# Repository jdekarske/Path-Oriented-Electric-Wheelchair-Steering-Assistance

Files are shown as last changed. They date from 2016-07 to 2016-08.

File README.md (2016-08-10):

# Path-Oriented-Electric-Wheelchair-Steering-Assistance
* See abstract for research background and see [TJOE](idkyet) for full research paper.

## Starting from scratch.
* See the bill of materials in appendix of paper for parts used in this project. 
* The "backup image" file can be flashed to an sd card using [this tutorial](http://computers.tutsplus.com/articles/how-to-flash-an-sd-card-for-raspberry-pi--mac-53600) or your favorite method.

## Adding to an existing system.
* Install the OpenCV library using [this tutorial](http://www.pyimagesearch.com/2016/04/18/install-guide-raspberry-pi-3-raspbian-jessie-opencv-3/).

## Using the scripts.
* Add run command `sudo python <script directory> &` to `etc/profile`, use ampersand to run script in background.
* Use `sudo raspi-config` and switch to "auto login command line" or errors will occur! 
* Use `live_sidewalk_recogize.py` for the intended application described by the research documents.
* Use `sidewalkrecognize.py` to analyze images and adjust range parameters.
* Use `videowatcher.py` to see frame by frame if omxplayer isn't working.
* Use `vsidewalkrecognize.py` to analyze videofiles.

# TODO (`live_sidewalk_recognize.py`):
* Find more graceful way to use `onbuttonpress()`.
* Add cliff detection. When the centroid falls below a certain vertical coordinate.
* Add shadow detection. See article: ["Shadow Detection and Removal from a Single Image Using LAB Color Space"](url=http://www.degruyter.com/view/j/cait.2013.13.issue-1/cait-2013-0009/cait-2013-0009.xml)
* Improve framerate/optimize.

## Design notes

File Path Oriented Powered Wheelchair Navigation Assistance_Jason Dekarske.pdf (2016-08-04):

Path Oriented Powered Wheelchair Navigation Assistance
Jason Dekarske, Devin R. Berg
University of Wisconsin – Stout

Introduction: Electric wheelchairs can greatly improve an individual’s life and independence. The literature indicates that 40% of patients using wheelchairs found it “difficult or impossible” to steer an electric wheelchair and up to half of patients would find it beneficial to have an added navigation system (Fehr et al., 2000). Wheelchair navigation systems, however, have seldom been implemented due to expense of the associated technologies and complexity of the components required. Horn summarizes that navigation systems used in “smart wheelchairs” during the past few decades include technologies such as infrared, sonar, laser, radar, and physical modalities (Horn, 2012). The research presented here aims to help people with disabilities navigate in a daytime, suburban or urban environment. Using a simple color camera, differences in the color and shape of the environment can be used to isolate a navigable path. Like lane keeping systems used in modern cars, the design presented here makes use of a passive interference system, to provide the user with direct navigational control, but aids in steering (Yu et al.,2008).

Materials and Methods: To minimize system cost, the materials selected are those commonly used in opensource hardware design. The Raspberry Pi 3 is used as the computational device with the Raspi camera module attached. The board runs Raspbian Jessie, the most recent operating system and a 10 Ah battery bank provides power. To analyze input, the Python programming language was used along with the OpenCV library to process images. Finally, as a proof of concept, an LED array provides visual feedback to the user. To identify the sidewalk, the software removes anything in the picture that doesn’t share similar appearance characteristics, then calculates the position of the centroid of the remaining shape. This determines whether the user is on path. To test the device, it was attached to a powered wheelchair and driven down the sidewalk. In one case, the wheelchair was manually driven according strictly to the path shown by the LED array. In another case, the wheelchair was pivoted from side to side to analyze the reaction by the device

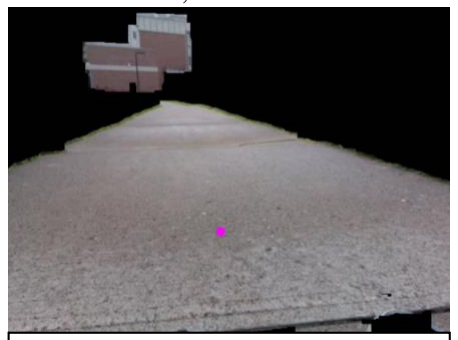
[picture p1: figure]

Results and Discussion: Case one was successful in terms of intervention.
Only when turning corners or navigating a split in the path did the subject have to divert from the device’s suggestion. Case two demonstrated that the user was able to complete a full turn with consistent tracking of the sidewalk for the entirety. In addition, the device kept accurate error logs and reported an average of near 6 frames per second over multiple trials while simultaneously recording video. The battery supplies power for approximately 5 hours, but the system could be integrated into the wheelchair’s power.

Conclusions: This navigation system represents a tool to help people that
use wheelchairs navigate their surroundings with greater confidence. This
prototype is sufficiently capable of indicating which part of the
environment is navigable. Implementation of this system can be modified to include an intervention into the control system of a powered wheelchair.

Acknowledgements: This work was completed as part of the Interdisciplinary Research Experiences in Robotics for Assistive Technology REU funded through NSF Award # CNS-1560219.

References:
Fehr, L., Langbein, W. E., & Skaar, S. B. (2000). Adequacy of power wheelchair control interfaces for persons with severe disabilities: A clinical survey. Journal Of Rehabilitation Research & Development, 37(3), 353.
Horn, O. (2012). Smart Wheelchairs: past and current trends. Systems and Computer Science, pp. 1-6.
Yu, B., Zhang, W., & Cai, Y. (2008). A Lane Departure Warning System based on Machine Vision. IEEE Pacific-Asia Workshop on Computational Intelligence and Industrial Application, pp. 197-201.

Figure 1. This screengrab shows the output of a sidewalk after calculating the centroid (pink circle). Only the largest part of the visible mask is considered.

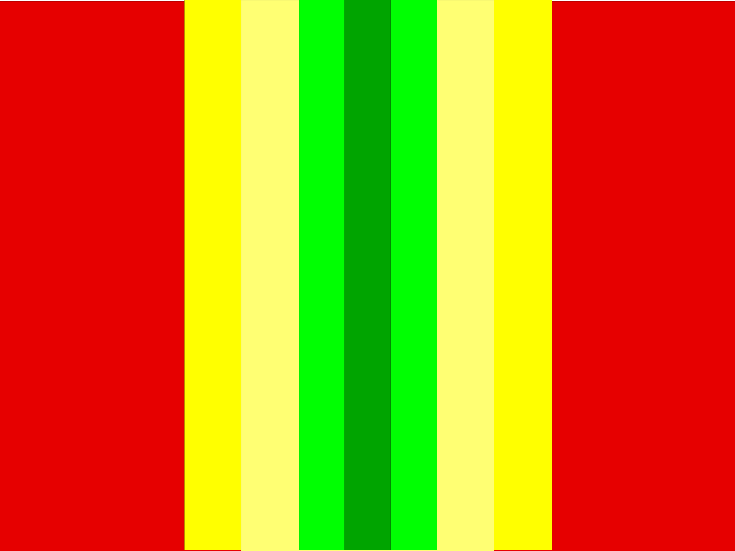
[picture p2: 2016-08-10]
pics/ranges.png

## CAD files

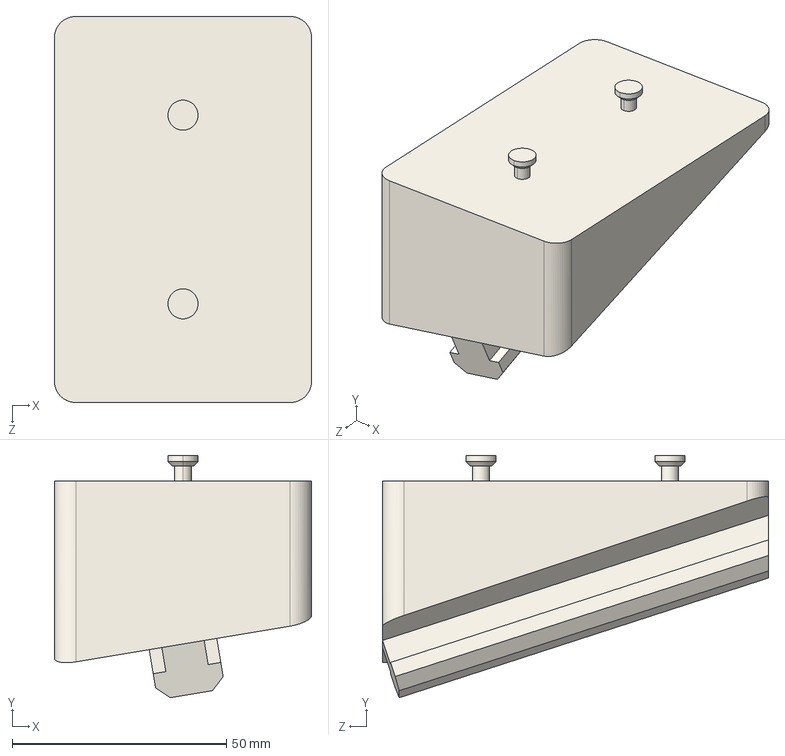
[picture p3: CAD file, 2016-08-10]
Raspi_mount.STEP
60.0 x 56.5 x 90.0 mm

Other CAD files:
Raspi_mount.SLDPRT

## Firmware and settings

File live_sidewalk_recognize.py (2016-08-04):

import RPi.GPIO as GPIO
import time
import io
import numpy as np
import cv2
import picamera
import logging

global menuv
menuv = 0
global buttonpress
buttonpress = 0

#logging setup
logging.basicConfig(format='\n%(asctime)s %(message)s', filename='/home/pi/REU/Path-Oriented-Electric-Wheelchair-Steering-Assistance/Output/data.log',level=logging.DEBUG)
logging.info('----Startup----')

#pin setup
GPIO.setmode(GPIO.BOARD)## Use board pin numbering
button   = 3
red_r    = 35
yellow_r2= 33
yellow_r = 31
green_r  = 29
green    = 23
green_l  = 21
yellow_l = 19
yellow_l2= 15
red_l    = 13
channels = [red_r, yellow_r2, yellow_r,
            green_r, green, green_l,
            yellow_l, yellow_l2, red_l]
GPIO.setup(channels, GPIO.OUT)
GPIO.setup(button, GPIO.IN)

#is there a better way to do this?
#signalling leds
def ledflash(t):
    GPIO.output(channels,False)
    GPIO.output(red_l,True)
    time.sleep(t)
    GPIO.output(yellow_l2,True)
    time.sleep(t)
    GPIO.output(yellow_l,True)
    time.sleep(t)
    GPIO.output(green_l,True)
    time.sleep(t)
    GPIO.output(green,True)
    time.sleep(t)
    GPIO.output(green_r,True)
    time.sleep(t)
    GPIO.output(yellow_r,True)
    time.sleep(t)
    GPIO.output(yellow_r2,True)
    time.sleep(t)
    GPIO.output(red_r,True)
    time.sleep(t)
    GPIO.output(red_r,False)
    time.sleep(t)
    GPIO.output(yellow_r2,False)
    time.sleep(t)
    GPIO.output(yellow_r,False)
    time.sleep(t)
    GPIO.output(green_r,False)
    time.sleep(t)
    GPIO.output(green,False)
    time.sleep(t)
    GPIO.output(green_l,False)
    time.sleep(t)
    GPIO.output(yellow_l,False)
    time.sleep(t)
    GPIO.output(yellow_l2,False)
    time.sleep(t)
    GPIO.output(red_l,False)
    time.sleep(.5)

def lederror():
    GPIO.output(channels,False)
    time.sleep(.1)
    GPIO.output(channels,True)
    time.sleep(.1)
    GPIO.output(channels,False)
    time.sleep(.1)
    GPIO.output(channels,True)
    time.sleep(.1)
    GPIO.output(channels,False)
    time.sleep(.1)
    GPIO.output(channels,True)
    time.sleep(.1)
    GPIO.output(channels,False)
    time.sleep(2)
        
    
def ledarray(Cx, Cy, center): #center at 320 make a config file for this
    GPIO.output(channels,False)
    if  (Cx < (480-center)): #160
        GPIO.output(red_l,True)
        logging.warning('Extreme left!')
    elif(Cx < (530-center)): #210
        GPIO.output(yellow_l2,True)
    elif(Cx < (580-center)): #260
        GPIO.output(yellow_l,True)
    elif(Cx < (620-center)): #300
        GPIO.output(green_l,True)
    elif(Cx < (660-center)): #340
        GPIO.output(green,True)
    elif(Cx < (700-center)): #380
        GPIO.output(green_r,True)
    elif(Cx < (750-center)): #430
        GPIO.output(yellow_r,True)
    elif(Cx < (800-center)): #480
        GPIO.output(yellow_r2,True)
    else:
        GPIO.output(red_r,True)
        logging.warning('Extreme right!')
     
def blink(color):
        GPIO.output(color,True)
        time.sleep(.1)
        GPIO.output(color,False)
        time.sleep(.1)

def main(center, record):

    #constants
    mode = np.array([65,10,6]) #inrange components for Lab. Found by doing a bunch of manual tests.
    totaltime = 0.0
    count = 0
    fps = 0.0
    resolution = (640, 480)
    totalfps = []
    global menuv #need these to communicate with the button
    global buttonpress
    
    #video recording set up
    fourcc = cv2.VideoWriter_fourcc(*'XVID')
    filename = '/home/pi/REU/Path-Oriented-Electric-Wheelchair-Steering-Assistance/Output/' + time.strftime('%Y%m%d_%H%M%S') + '.avi'
    out = cv2.VideoWriter(filename,fourcc, 6.0, (640,480))
    

    buttonpress = 0
    stream = io.BytesIO()
    with picamera.PiCamera(resolution=resolution) as camera:
        #camera.start_preview() #enable to see camera on screen, doesn't work with CLI
        while(buttonpress == 0): # and camera._check_camera_open()
            camera.capture(stream, format='jpeg')
            e1 = cv2.getTickCount() #timer

            # Construct a numpy array from the stream
            data = np.fromstring(stream.getvalue(), dtype=np.uint8)

            # "Decode" the image from the array
            image = cv2.imdecode(data, 1)
            stream = io.BytesIO()

            # convert to lab format
            lab = cv2.cvtColor(image, cv2.COLOR_BGR2Lab)
             
            # establish roi in middle of image
            rows, columns, c = lab.shape
            middleroi = lab[(int(rows*.8)):rows , (int(columns*.33)):(int(columns*.66))]

            #establish range of acceptable colors
            mean = cv2.mean(middleroi)
            lowermean = np.array([mean[0]-mode[0],mean[1]-mode[1],mean[2]-mode[2]])
            uppermean = np.array([mean[0]+mode[0],mean[1]+mode[1],mean[2]+mode[2]])

            #check which part of image is in range, then filter out smaller pieces
            mask = cv2.inRange(lab, lowermean, uppermean)
            res = cv2.bitwise_and(image,image, mask= mask)
            emask1 = cv2.erode(mask,None, iterations=8)
            emask = cv2.dilate(emask1,None, iterations=12)

            #assemble better shape, select biggest area
            areas = []
            _, contours, hierarchy = cv2.findContours(emask.copy(),cv2.RETR_EXTERNAL,cv2.CHAIN_APPROX_SIMPLE)
            for i, c in enumerate(contours):
                area = cv2.contourArea(c)
                areas.append(area)
            biggest = np.argmax(areas)

            # compute the center of the contour
            M = cv2.moments(contours[biggest][:])
            cX = int(M["m10"] / M["m00"])
            cY = int(M["m01"] / M["m00"])
            ledarray(cX,cY,center)

            # draw the contour and center of the shape on the image
            cv2.circle(image, (cX, cY), 7, (255, 0, 255), -1)
#            cv2.drawContours(image, contours, biggest, (0,255,0), 1) #outlines the largest contour, not necessary
            eroded = cv2.bitwise_and(image,image, mask= emask)
#            cv2.imshow('eroded',eroded)

            #end timer, display frames per second taking the average over 10 frames
            e2 = cv2.getTickCount()
            looptime = (e2 - e1)/ cv2.getTickFrequency()
            totaltime += looptime
            count += 1
            if count > 10: 
                fps = count/totaltime
                count = 0
                totaltime = 0
                totalfps.append(fps)
                logging.info('fps: %s',fps)
#            cv2.putText(eroded,str(int(fps)),(50,50),cv2.FONT_HERSHEY_SIMPLEX,1,(255,255,255),2)
            
        #record video
            if(record == 1):
                out.write(eroded)
    GPIO.output(channels,False)
    out.release()
    meanfps = np.mean(totalfps)
    logging.info('Average frames per second: %s', meanfps)
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

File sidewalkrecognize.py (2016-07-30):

import numpy as np
import cv2
# from picamera.array import PiRGBArray
# from picamera import PiCamera
import argparse

# construct the argument parse and parse the arguments
ap = argparse.ArgumentParser()
ap.add_argument("-i", "--image", help = "path to the image")
ap.add_argument("-m", "--mode", help = "HSV or Lab mode")
args = vars(ap.parse_args())

# load the image
image = cv2.imread(args["image"])


# blur then convert to LAB format
blurred = cv2.GaussianBlur(image, (5, 5), 0)

#check mode argument
if args["mode"] == 'HSV':
    colormode = np.array(['H','S','V'])
    lab = cv2.cvtColor(blurred, cv2.COLOR_RGB2HSV)
elif args["mode"] == 'Lab':
    colormode = np.array(['L','a','b'])
    lab = cv2.cvtColor(blurred, cv2.COLOR_RGB2Lab)
else:
    print("unsupported mode")

#empty function
def nothing(x):
    cv2.destroyWindow('eroded')

# create control window for changing parameters
cv2.namedWindow('control')
cv2.createTrackbar(colormode[0],'control',65,300,nothing)
cv2.createTrackbar(colormode[1],'control',5,300,nothing)
cv2.createTrackbar(colormode[2],'control',11,300,nothing)
cv2.createTrackbar('I','control',10,20,nothing)  
 
# establish roi in middle of image
rows, columns, c = lab.shape
middleroi = lab[(int(rows*.8)):rows , (int(columns*.33)):(int(columns*.66))]
mean,stddev = cv2.meanStdDev(middleroi)
##print(mean)
##print(stddev)

#check for shadow above roi
##shad_roi = lab[(rows*.6):(rows*.8) , (columns*.33):(columns*.66)]
##shad_mean,shad_stddev = cv2.meanStdDev(shad_roi)
##print(shad_mean)
##print(shad_stddev)

mode = np.array([65,5,11])
I = 10
area = np.array(np.zeros(1000)) #this should be better

while(1):
    k = cv2.waitKey(2) & 0xFF
    if k == 27:
        break

    lowermean = np.array([mean[0]-mode[0],mean[1]-mode[1],mean[2]-mode[2]])
    uppermean = np.array([mean[0]+mode[0],mean[1]+mode[1],mean[2]+mode[2]])

    #check which part of image is in range, then filter out smaller pieces
    mask = cv2.inRange(lab, lowermean, uppermean)
    res = cv2.bitwise_and(image,image, mask= mask)
    emask1 = cv2.erode(mask,None, iterations=9)
    emask = cv2.dilate(emask1,None, iterations=11)

    #assemble better shape
    areas = []
    _, contours, hierarchy = cv2.findContours(emask.copy(),cv2.RETR_EXTERNAL,cv2.CHAIN_APPROX_SIMPLE)
    cnt = enumerate(contours)
    for i, c in cnt:
        area = cv2.contourArea(c)
        areas.append(area)
    biggest = np.argmax(areas)

    # compute the center of the contour
    M = cv2.moments(contours[biggest][:])
    cX = int(M["m10"] / M["m00"])
    cY = int(M["m01"] / M["m00"])

    # draw the contour and center of the shape on the image
    cv2.drawContours(image, contours, biggest, (0,255,0), 1)
    cv2.circle(image, (cX, cY), 7, (255, 255, 255), -1)
    cv2.putText(image, "center", (cX - 20, cY - 20),
    cv2.FONT_HERSHEY_SIMPLEX, 0.5, (255, 255, 255), 2)


    
    eroded = cv2.bitwise_and(image,image, mask= emask)

    #get trackbar value
    mode[0] = cv2.getTrackbarPos(colormode[0],'control')
    mode[1] = cv2.getTrackbarPos(colormode[1],'control')
    mode[2] = cv2.getTrackbarPos(colormode[2],'control')
    I = cv2.getTrackbarPos('I','control')
    cv2.imshow('eroded',eroded)


def appendtxt(var):
    myfile.write(str(var))
    myfile.write("\t")

#not sure how to consolidate this, testing for how to apply an auto filter. will be analyzed in excel anyway
with open("record.txt", "a") as myfile:
    appendtxt(area)
##    appendtxt(mean[0])
##    appendtxt(stddev[0]) #Stddev of sample~~if this is large the range should have to be bigger
##    appendtxt(mean[1])
##    appendtxt(stddev[1])
##    appendtxt(mean[2])
##    appendtxt(stddev[2])
##    appendtxt(mode[0]) #L
##    appendtxt(mode[1]) #a
##    appendtxt(mode[2]) #b
    myfile.write("\n")
cv2.destroyAllWindows()

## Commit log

2016-07-24 fixed mode issue, collected data for auto adjustments
    [recordspdsht.ods, recordspdsht.xlsx]
2016-07-26 added centroid and led fuctionality
2016-07-26 added fun led blinky things
2016-07-30 file organization and bugfixes
    [recordspdsht.ods, recordspdsht.xlsx]
2016-08-08 added solidworks part
    [Raspi_mount.SLDPRT]
2016-08-10 added .step file
    [Raspi_mount.SLDPRT, Raspi_mount.STEP]
